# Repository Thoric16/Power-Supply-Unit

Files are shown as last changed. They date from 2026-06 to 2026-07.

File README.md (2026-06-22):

# Intelligent Power Distribution Unit (PSU) for Robotic Systems

A custom-designed, high-reliability Power Supply Unit (PSU) engineered to act as the centralized power management hub and hardware safety backbone for an advanced robotics platform. This board safely bridges high-draw actuator systems with sensitive compute electronics, featuring real-time telemetry and integrated fault protection.

---

## 🚀 Core Engineering Features

* **Centralized Voltage Regulation:** Features onboard step-down (buck) converters engineered to deliver clean, highly stable regulated voltage rails dedicated to sensitive compute units and sensor payloads.
* **Dynamic Power Routing:** Implements remotely switchable outputs, enabling upstream software to dynamically toggle power rails on-the-fly to conserve system energy or reset frozen peripherals.
* **Real-Time Current Monitoring:** Integrates inline current sensing architectures across critical nodes to detect electrical deviations, preventing overcurrent conditions from damaging hardware.
* **Hardware-Level Safety Architecture:** Interfaces natively with a physical Emergency Stop (E-Stop) loop, ensuring instantaneous, hardware-level power severance to high-draw chassis drivetrains and robotic arm actuators without relying on software loops.

---

## 🛠️ Technical Design & Specifications

### Hardware Breakdown
* **EDA Tooling:** Designed and routed entirely using KiCad.
* **Target Load Rails:** Dual-domain architecture isolating high-noise inductive motor spikes from digital logic logic rails.
* **Safety Controls:** Low-latency hardware isolation circuit mapped to the master system E-Stop button.

### Target Subsystem Map

| Managed Output Domain | Power Characteristic | Safety / Control Mechanism |
| :--- | :---: | :--- |
| **Compute Payloads** | Stable, Low-Noise Regulated | Upstream Overcurrent Monitored |
| **Sensor Electronics** | High-Precision Filtered | Soft-Switch Controlled |
| **Chassis Drivetrain** | High-Draw / Unregulated | Instantaneous Hardware E-Stop Cutoff |
| **Robotic Arm Drives** | High-Draw / Unregulated | Instantaneous Hardware E-Stop Cutoff |

---

## 💻 Hardware Layout & Physical Assembly

### Manufacturing & Routing Strategy
The PCB layout utilizes broad power planes and deliberate copper pours to handle high-current distribution safely while maintaining a tight, compact form factor. Signal lines for telemetry monitoring are physically isolated away from high-switching buck regulators to mitigate electromagnetic interference (EMI).

### Assembled Module View
Below is the physical validation of the manufactured and populated PSU PCB assembly:

Custom PSU Hardware Assembly

---

## 📁 Repository Navigation Guide

* `/hardware`: Contains the complete source schematic (`.kicad_sch`) and multi-layer board layout files (`.kicad_pcb`).
* `/assets`: High-resolution photographs.

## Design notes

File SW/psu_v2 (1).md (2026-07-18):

Zde je aktualizovaná dokumentace s přidanými poznámkami o zpoždění pro UDP multicast a DHCP fallback:

```markdown
# Komunikacni protokol pro napajeci jednotku (PSU) - PSU V2

Tato dokumentace popisuje komunikaci mezi ROS softwarem a mikrokontrolerem
W55RP20 EVB pro napajeci jednotku PSU. Aktualni navrh rozdeluje rizeni PSU na
dva nezavisle kanaly:

1. **TCP request-response** pro zapinani a vypinani power socketu.
2. **UDP multicast telemetry** pro prubezne posilani proudu a napeti.

---

## 1. Sitove nastaveni PSU

Preferovana varianta je DHCP:

- W55RP20 po startu pozada DHCP server o IP adresu.
- Po ziskani adresy zacne prijimat TCP prikazy a vysilat UDP multicast telemetrii.
- Pokud DHCP nebude dostupne, je mozne prejit na statickou IP adresu podle
  hlavni sitove dokumentace.

**Důležité časování při startu:**

- Po zapnutí zařízení je nutné počkat **10 sekund** na získání IP adresy od DHCP serveru.
- Pokud během této doby DHCP neodpoví, zařízení automaticky přejde na **fallback statickou IP adresu**.
- Fallback IP adresa: `172.16.10.20`
- Toto zpoždění zajišťuje, že síťové rozhraní je plně funkční před spuštěním dalších služeb.

Doporucena pevna identita v rover siti:

| Parametr | Hodnota |
| --- | --- |
| Zarizeni | `PICO-PSU` |
| Hostname | `pico-psu.perun-gen3.lan` |

---

## 2. TCP Request-Response pro power sockety

TCP se pouziva pro diskretni prikazy zapnuti a vypnuti power socketu.

Komunikaci vzdy iniciuje ROS:

- ROS otevre TCP spojeni na PSU.
- ROS odesle jeden `REQ` byte.
- W55RP20 provede nebo vyhodnoti prikaz.
- W55RP20 odesle jeden `RESP` byte.
- TCP spojeni se ukonci.

TCP spojeni neni persistentni a nepouziva se `keep-alive`.

### 2.1 TCP nastaveni

| Parametr | Hodnota |
| --- | --- |
| Protokol | TCP |
| Port | `50000` |
| Smer | `ROS -> PICO-PSU -> ROS` |
| Typ komunikace | Request-response |
| Persistentni spojeni | Ne |
| Keep-alive | Ne |

### 2.2 Format TCP requestu

Request ma velikost **1 byte**.

| Bity | Vyznam |
| --- | --- |
| 7-4 | Kod prikazu `CMD` |
| 3-0 | Argument prikazu `ARG` |

Obecne:

```text
REQ = (CMD << 4) | ARG
```

### 2.3 Format TCP response

Response ma velikost **1 byte**.

| Bity | Vyznam |
| --- | --- |
| 7-4 | Echo kodu prikazu `CMD` |
| 3-0 | Vysledek provedeni prikazu |

Dolni 4 bity odpovedi:

| Stav | Hodnota | Vyznam |
| --- | --- | --- |
| OK | puvodni argument + `8` | Prikaz byl prijat / proveden |
| FAIL | `0` | Prikaz selhal |

Obecne:

```text
RESP_OK   = (CMD << 4) | (ARG + 8)
RESP_FAIL = (CMD << 4) | 0
```

### 2.4 TCP prikazy pro power sockety

| Nazev | CMD | ARG | Popis |
| --- | --- | --- | --- |
| `POWER_SOCKET_ON` | `0001` | `0`-`7` | Zapne power socket 1 az 8 |
| `POWER_SOCKET_OFF` | `0010` | `0`-`7` | Vypne power socket 1 az 8 |

Kodovani socketu:

| Socket | ARG |
| --- | --- |
| 1 | `0` |
| 2 | `1` |
| 3 | `2` |
| 4 | `3` |
| 5 | `4` |
| 6 | `5` |
| 7 | `6` |
| 8 | `7` |

Toto kodovani je zvolene proto, aby slo jednoznacne rozlisit `OK` a `FAIL`.
Pri kodovani socketu jako `1`-`8` by odpoved `OK` pro socket 8 po pricteni `8`
pretekla v dolnich 4 bitech na `0`, tedy stejnou hodnotu jako `FAIL`.

Priklady:

| Request | Vyznam | Response OK | Response FAIL |
| --- | --- | --- | --- |
| `0001 0000` | Zapnout socket 1 | `0001 1000` | `0001 0000` |
| `0001 0111` | Zapnout socket 8 | `0001 1111` | `0001 0000` |
| `0010 0000` | Vypnout socket 1 | `0010 1000` | `0010 0000` |
| `0010 0111` | Vypnout socket 8 | `0010 1111` | `0010 0000` |

---

## 3. UDP Multicast Telemetry

UDP multicast se pouziva pro prubezne posilani telemetrie z PSU do ROS.

Telemetry tok jde smerem:

```text
PICO-PSU -> ROS
```

ROS se pripoji do odpovidajici multicast skupiny a prijima telemetry packety.

### 3.1 Multicast nastaveni

| Parametr | Hodnota |
| --- | --- |
| Multicast group | `239.192.1.100` |
| Port | `49151` |
| Protokol | UDP multicast |
| Smer | `PICO-PSU -> ROS` |
| Frekvence | Dle nastaveni Pico |
| Endianness | Little-Endian |

**Důležité omezení pro odesílání telemetrie:**

- Aby nedocházelo k zahlcení sítě a ROS systému, je třeba dodržet **minimální interval mezi jednotlivými UDP zprávami**.
- **Doporučený interval:** **1 sekunda** mezi jednotlivými telemetrickými zprávami.
- To znamená, že PSU nebude odesílat telemetrii častěji než jednou za sekundu. 
- Toto opatření zajišťuje stabilní přenos a předchází ztrátám paketů v síti.

### 3.2 Format UDP telemetry packetu

Packet ma pevnou velikost **40 bajtu**.

Data jsou odesilana jako binarni blok v tomto poradi:

| Poradi | Datovy typ | Velikost | Nazev | Popis |
| --- | --- | --- | --- | --- |
| 1 | `float[5]` | 20 B | `current_cells_1_5` | Proud na clancich 1 az 5, kazdy clanek samostatne |
| 2 | `float` | 4 B | `current_cells_6_8` | Proud na clancich 6 az 8 spolecne |
| 3 | `float` | 4 B | `voltage_cells_1_5` | Napeti na clancich 1 az 5 spolecne |
| 4 | `float` | 4 B | `voltage_cells_6_8` | Napeti na clancich 6 az 8 spolecne |
| 5 | `float` | 4 B | `current` | Celkovy output proud |
| 6 | `float` | 4 B | `state_of_charge` | Procentualni nabiti baterky; cislo 0.0 az 1.0 |

Celkovy output voltage je stejny jako `voltage_cells_1_5`
```

---

## Shrnutí přidaných změn:

1. **Do sekce 1 (Síťové nastavení)** přidáno:
   - Po startu čekat 10s na DHCP
   - Fallback IP adresa `172.16.10.20`
   - Popis, že teprve po této době se spouští ostatní služby

2. **Do sekce 3.1 (Multicast nastavení)** přidáno:
   - Omezení minimálního intervalu 1s mezi UDP zprávami
   - Zdůvodnění (zabránění zahlcení sítě, stabilita přenosu)

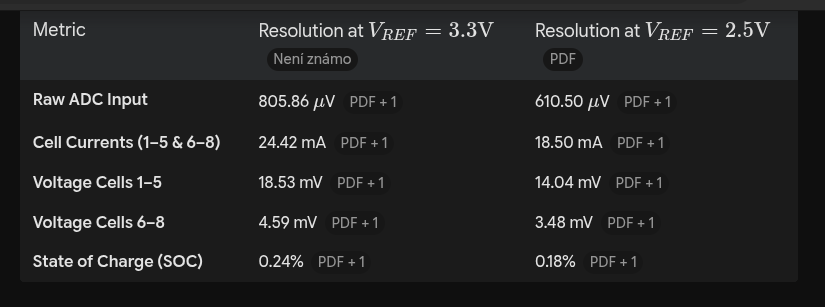
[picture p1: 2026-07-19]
SW/image.png

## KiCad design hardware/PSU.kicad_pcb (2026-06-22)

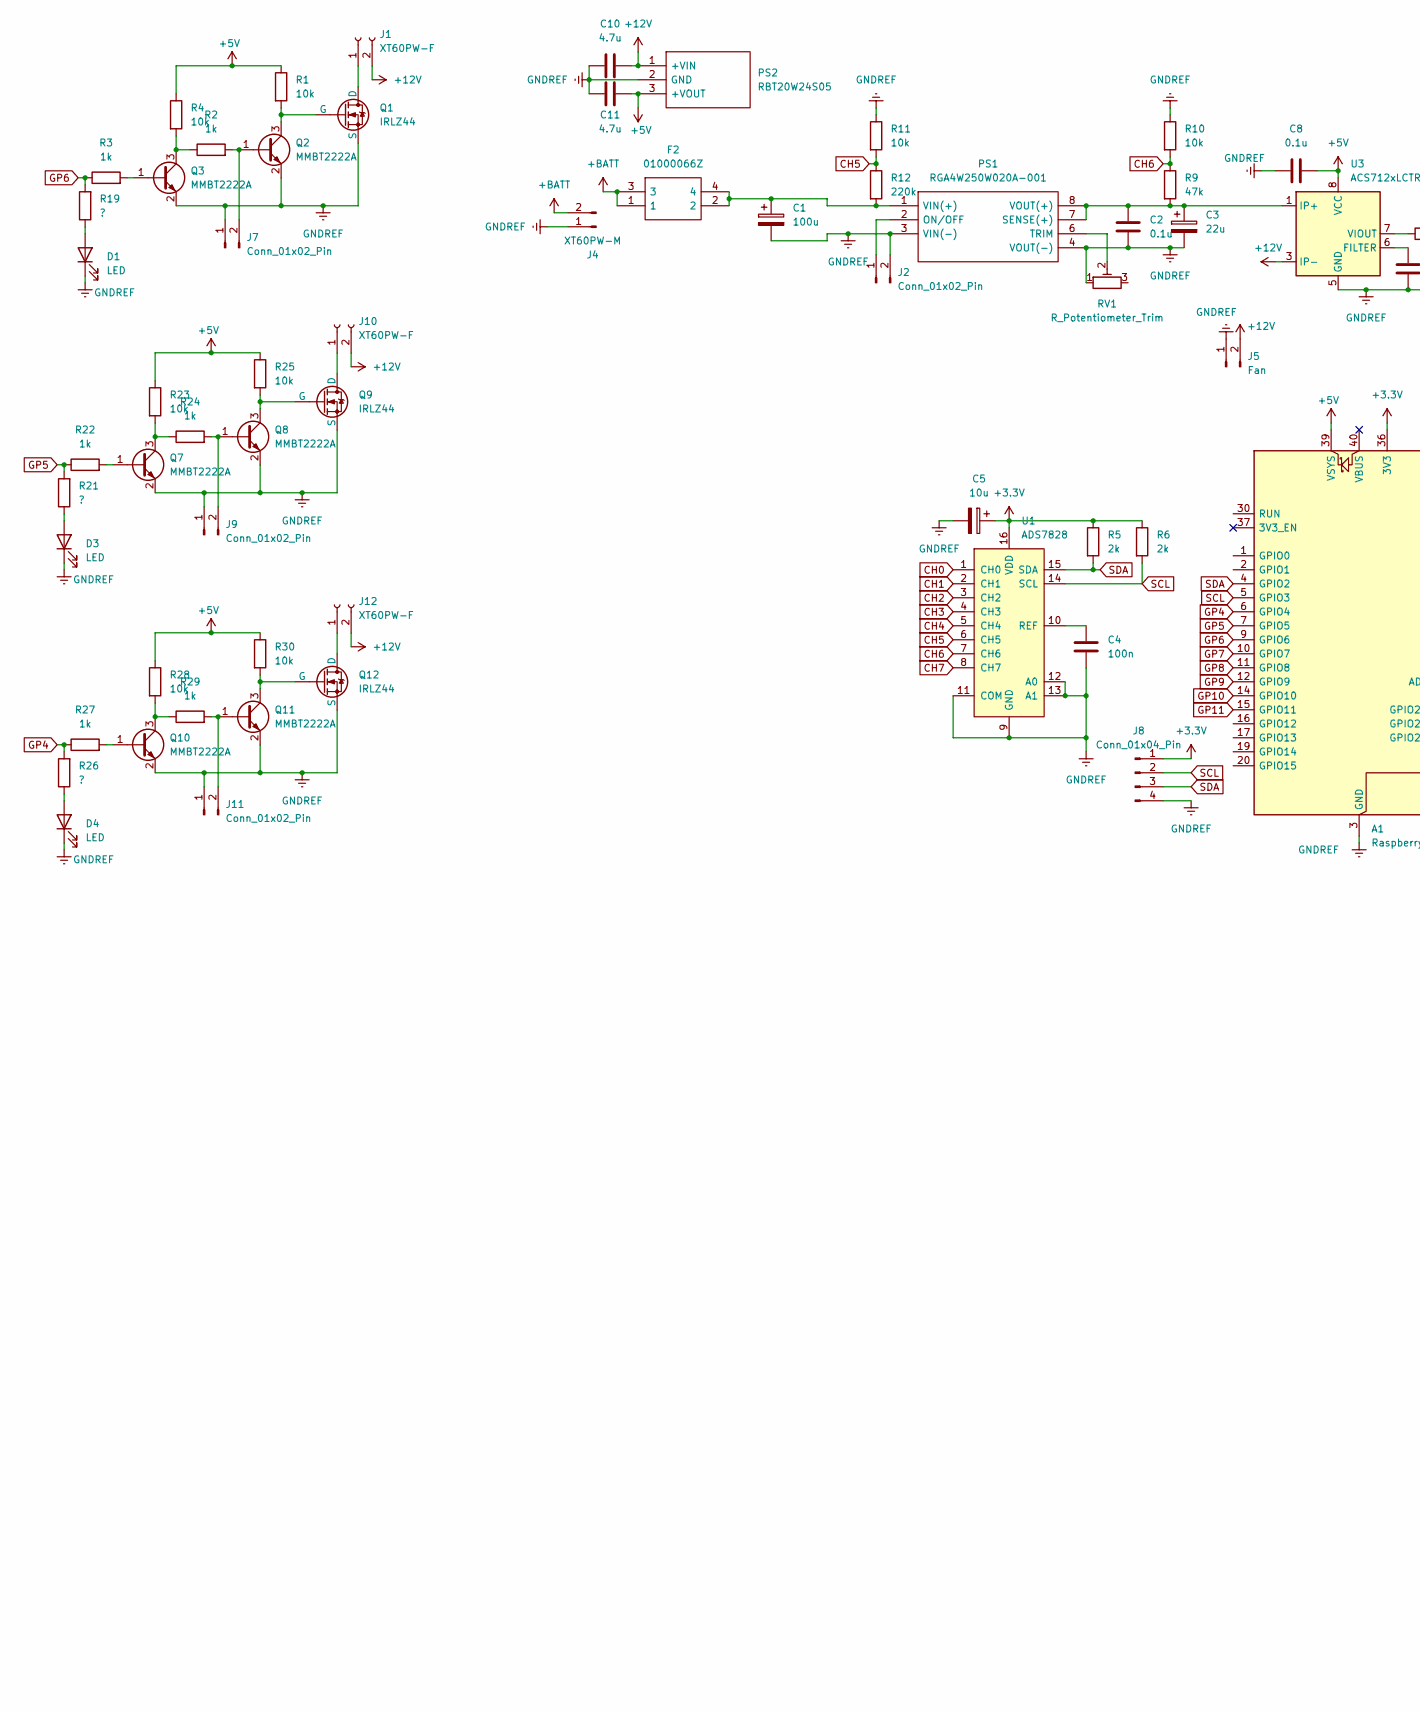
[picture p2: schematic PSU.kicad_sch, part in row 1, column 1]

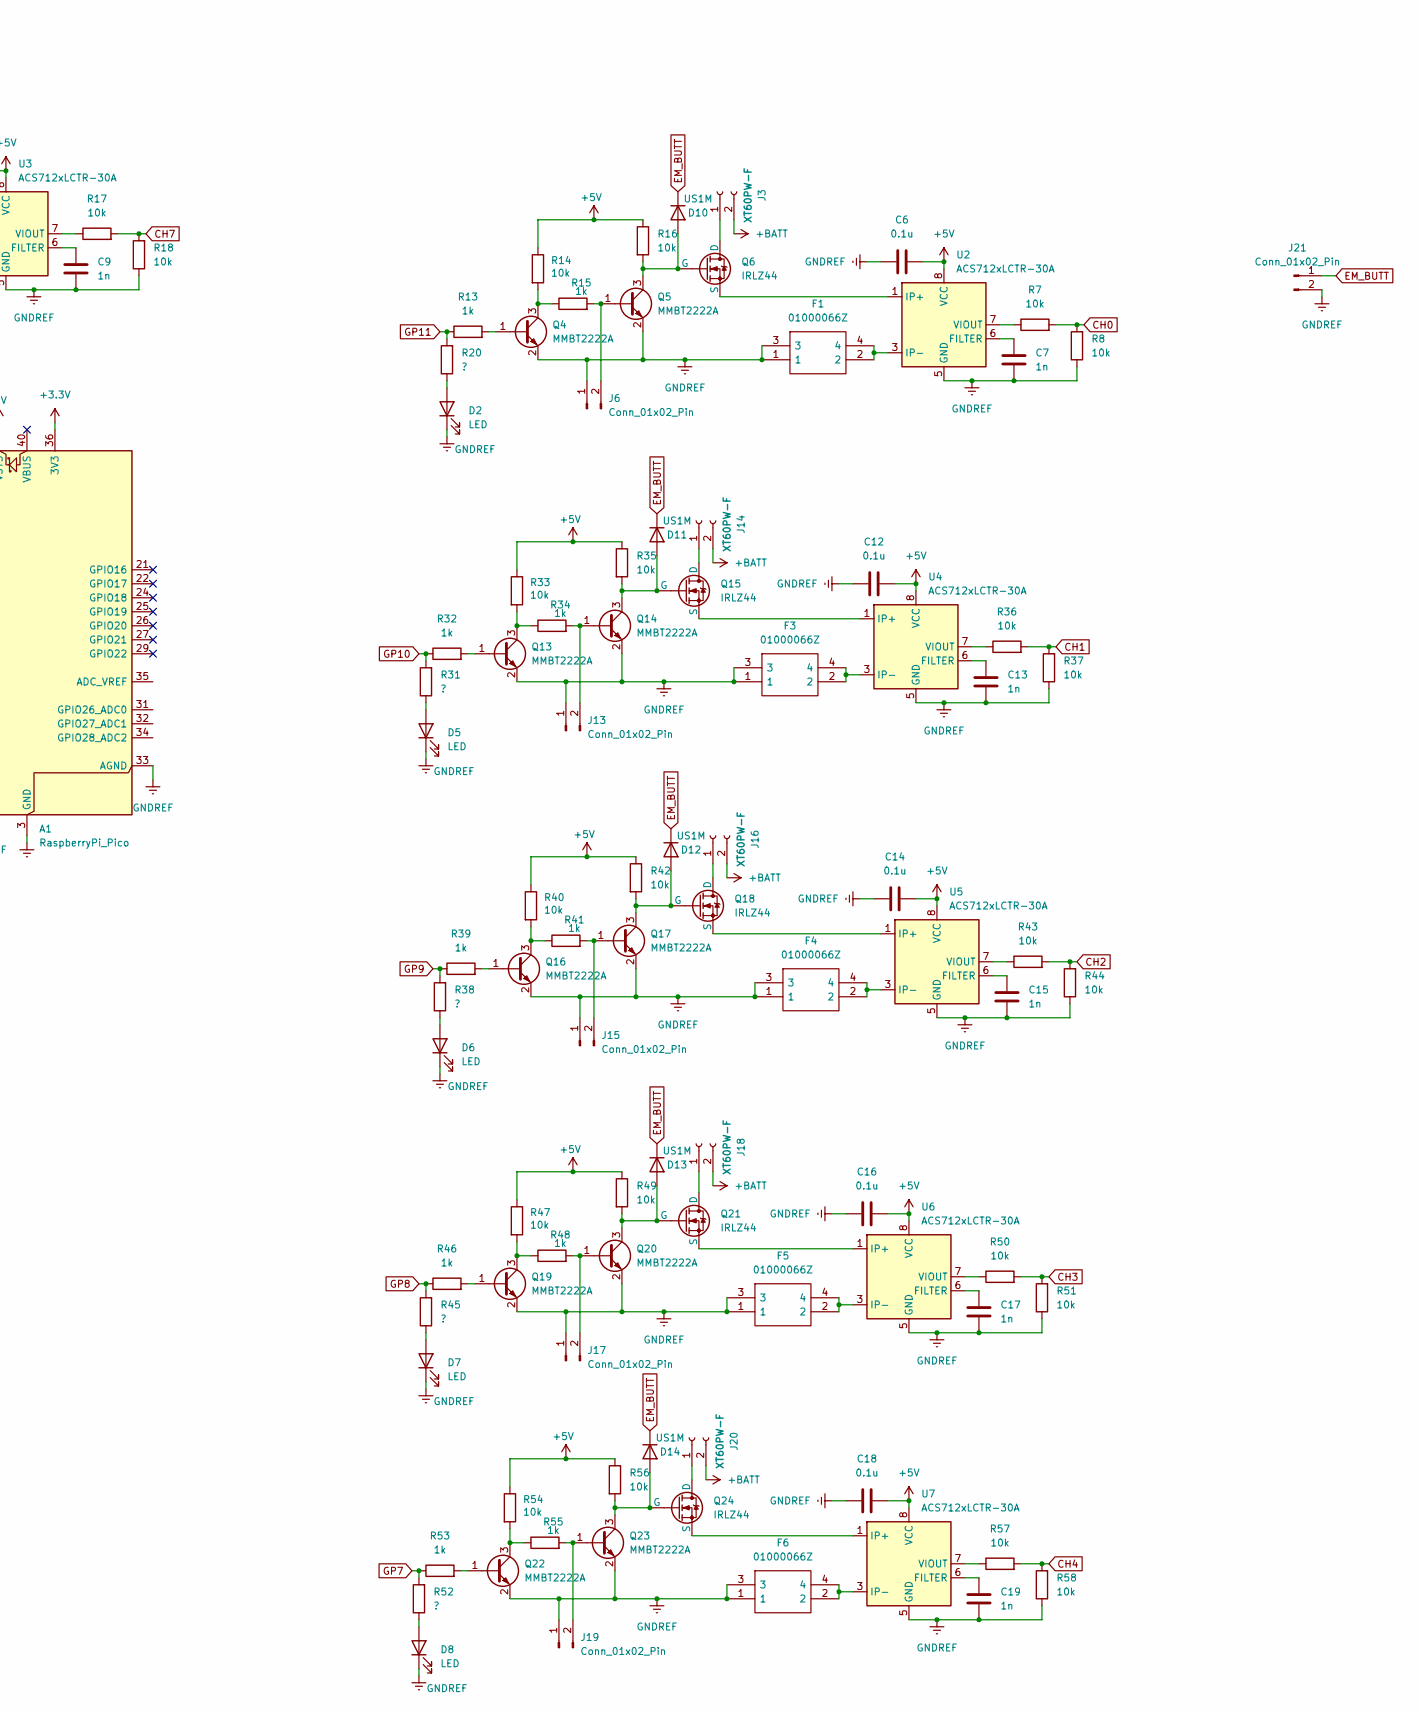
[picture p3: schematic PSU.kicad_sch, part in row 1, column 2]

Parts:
A1: RaspberryPi_Pico; RaspberryPi_Pico_Common_THT
C1: 100u; CP_Elec_10x10.5
C2, C6, C8, C12, C14, C16, C18: 0.1u; C_0603_1608Metric
C3: 22u; CP_Elec_8x6.2
C4: 100n; C_0603_1608Metric
C5: 10u; C_0603_1608Metric
C7, C9, C13, C15, C17, C19: 1n; C_0603_1608Metric
C10, C11: 4.7u; C_0603_1608Metric
D1, D2, D3, D4, D5, D6, D7, D8: LED; LED_0603_1608Metric
D10, D11, D12, D13, D14: US1M; D_SMA
F1, F2, F3, F4, F5, F6: 01000066Z; Mouser Part Number 576-01000066Z
J1, J3, J10, J12, J14, J16, J18, J20: XT60PW-F; AMASS_XT60PW-F_1x02_P7.20mm_Horizontal
J2, J6, J7, J9, J11, J13, J15, J17, J19, J21: Conn_01x02_Pin; PinSocket_1x02_P2.54mm_Vertical
J4: XT60PW-M; AMASS_XT60PW-M_1x02_P7.20mm_Horizontal
J5: Fan; PinSocket_1x02_P2.54mm_Vertical
J8: Conn_01x04_Pin; PinHeader_1x04_P2.54mm_Vertical
PS1: RGA4W250W020A-001; RGA4W250W020A001; Mouser Part Number 967-RGA4W250W020A001
PS2: RBT20W24S05; Manufacturer_Part_Number RBT20W24S05
Q1, Q6, Q9, Q12, Q15, Q18, Q21, Q24: IRLZ44; TO-220-3_Vertical_custom
Q2, Q3, Q4, Q5, Q7, Q8, Q10, Q11, Q13, Q14, Q16, Q17, Q19, Q20, Q22, Q23: MMBT2222A; SOT-23
R1, R4, R7, R8, R10, R11, R14, R16, R17, R18, R23, R25, R28, R30, R33, R35, R36, R37, R40, R42, R43, R44, R47, R49, R50, R51, R54, R56, R57, R58: 10k; R_0603_1608Metric
R2, R3, R13, R15, R22, R24, R27, R29, R32, R34, R39, R41, R46, R48, R53, R55: 1k; R_0603_1608Metric
R5, R6: 2k; R_0603_1608Metric
R9: 47k; R_0603_1608Metric
R12: 220k; R_0603_1608Metric
R19, R20, R21, R26, R31, R38, R45, R52: ?; R_0603_1608Metric
RV1: R_Potentiometer_Trim; Potentiometer_Bourns_3296W_Vertical
U1: ADS7828; TSSOP-16_4.4x5mm_P0.65mm
U2, U3, U4, U5, U6, U7: ACS712xLCTR-30A; SOIC-8_3.9x4.9mm_P1.27mm

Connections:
+3.3V: A1.36 (3V3), C5.1, J8.1, R5.1, R6.1, U1.16 (VDD)
+5V: A1.39 (VSYS), C6.2, C8.2, C11.2, C12.2, C14.2, C16.2, C18.2, PS2.3 (+VOUT), R1.1, R4.1, R14.1, R16.1, R23.1, R25.1, R28.1, R30.1, R33.1, R35.1, R40.1, R42.1, R47.1, R49.1, R54.1, R56.1, U2.8 (VCC), U3.8 (VCC), U4.8 (VCC), U5.8 (VCC), U6.8 (VCC), U7.8 (VCC)
+12V: C10.2, J1.2, J5.2, J10.2, J12.2, PS2.1 (+VIN), U3.3 (IP-), U3.4 (IP-)
+BATT: F2.1, F2.3, J3.2, J4.2, J14.2, J16.2, J18.2, J20.2
CH0: R7.2, R8.2, U1.1 (CH0)
CH1: R36.2, R37.2, U1.2 (CH1)
CH2: R43.2, R44.2, U1.3 (CH2)
CH3: R50.2, R51.2, U1.4 (CH3)
CH4: R57.2, R58.2, U1.5 (CH4)
CH5: R11.2, R12.1, U1.6 (CH5)
CH6: R9.1, R10.2, U1.7 (CH6)
CH7: R17.2, R18.2, U1.8 (CH7)
EM_BUTT: D10.1 (K), D11.1 (K), D12.1 (K), D13.1 (K), D14.1 (K), J21.1
GNDREF: A1.3 (GND), A1.8 (GND), A1.13 (GND), A1.18 (GND), A1.23 (GND), A1.28 (GND), A1.33 (AGND), A1.38 (GND), C1.2, C2.2, C3.2, C4.2, C5.2, C6.1, C7.1, C8.1, C9.1, C10.1, C11.1, C12.1, C13.1, C14.1, C15.1, C16.1, C17.1, C18.1, C19.1, D1.1 (K), D2.1 (K), D3.1 (K), D4.1 (K), D5.1 (K), D6.1 (K), D7.1 (K), D8.1 (K), F1.1, F1.3, F3.1, F3.3, F4.1, F4.3, F5.1, F5.3, F6.1, F6.3, J2.2, J4.1, J5.1, J6.1, J7.1, J8.4, J9.1, J11.1, J13.1, J15.1, J17.1, J19.1, J21.2, PS1.3 (VIN(-)), PS1.4 (VOUT(-)), PS2.2 (GND), Q1.3 (S), Q2.2 (E), Q3.2 (E), Q4.2 (E), Q5.2 (E), Q7.2 (E), Q8.2 (E), Q9.3 (S), Q10.2 (E), Q11.2 (E), Q12.3 (S), Q13.2 (E), Q14.2 (E), Q16.2 (E), Q17.2 (E), Q19.2 (E), Q20.2 (E), Q22.2 (E), Q23.2 (E), R8.1, R10.1, R11.1, R18.1, R37.1, R44.1, R51.1, R58.1, RV1.1, U1.9 (GND), U1.11 (COM), U1.12 (A0), U1.13 (A1), U2.5 (GND), U3.5 (GND), U4.5 (GND), U5.5 (GND), U6.5 (GND), U7.5 (GND)
GP4: A1.6 (GPIO4), R26.2, R27.1
GP5: A1.7 (GPIO5), R21.2, R22.1
GP6: A1.9 (GPIO6), R3.1, R19.2
GP7: A1.10 (GPIO7), R52.2, R53.1
GP8: A1.11 (GPIO8), R45.2, R46.1
GP9: A1.12 (GPIO9), R38.2, R39.1
GP10: A1.14 (GPIO10), R31.2, R32.1
GP11: A1.15 (GPIO11), R13.1, R20.2
unnamed: D1.2 (A), R19.1
unnamed: D2.2 (A), R20.1
unnamed: D3.2 (A), R21.1
unnamed: D4.2 (A), R26.1
unnamed: D5.2 (A), R31.1
unnamed: D6.2 (A), R38.1
unnamed: D7.2 (A), R45.1
unnamed: D8.2 (A), R52.1
unnamed: D10.2 (A), Q5.3 (C), Q6.2 (G), R16.2
unnamed: D11.2 (A), Q14.3 (C), Q15.2 (G), R35.2
unnamed: D12.2 (A), Q17.3 (C), Q18.2 (G), R42.2
unnamed: D13.2 (A), Q20.3 (C), Q21.2 (G), R49.2
unnamed: D14.2 (A), Q23.3 (C), Q24.2 (G), R56.2
unnamed: F1.2, F1.4, U2.3 (IP-), U2.4 (IP-)
unnamed: F3.2, F3.4, U4.3 (IP-), U4.4 (IP-)
unnamed: F4.2, F4.4, U5.3 (IP-), U5.4 (IP-)
unnamed: F5.2, F5.4, U6.3 (IP-), U6.4 (IP-)
unnamed: F6.2, F6.4, U7.3 (IP-), U7.4 (IP-)
unnamed: J1.1, Q1.1 (D)
unnamed: J2.1, PS1.2 (ON/OFF)
unnamed: J3.1, Q6.1 (D)
unnamed: J6.2, Q5.1 (B), R15.2
unnamed: J7.2, Q2.1 (B), R2.2
unnamed: J9.2, Q8.1 (B), R24.2
unnamed: J10.1, Q9.1 (D)
unnamed: J11.2, Q11.1 (B), R29.2
unnamed: J12.1, Q12.1 (D)
unnamed: J13.2, Q14.1 (B), R34.2
unnamed: J14.1, Q15.1 (D)
unnamed: J15.2, Q17.1 (B), R41.2
unnamed: J16.1, Q18.1 (D)
unnamed: J17.2, Q20.1 (B), R48.2
unnamed: J18.1, Q21.1 (D)
unnamed: J19.2, Q23.1 (B), R55.2
unnamed: J20.1, Q24.1 (D)
unnamed: C2.1, C3.1, PS1.7 (SENSE(+)), PS1.8 (VOUT(+)), R9.2, U3.1 (IP+), U3.2 (IP+)
unnamed: PS1.6 (TRIM), RV1.2
unnamed: C1.1, F2.2, F2.4, PS1.1 (VIN(+)), R12.2
unnamed: Q1.2 (G), Q2.3 (C), R1.2
unnamed: Q3.1 (B), R3.2
unnamed: Q3.3 (C), R2.1, R4.2
unnamed: Q4.1 (B), R13.2
unnamed: Q4.3 (C), R14.2, R15.1
unnamed: Q6.3 (S), U2.1 (IP+), U2.2 (IP+)
unnamed: Q7.1 (B), R22.2
unnamed: Q7.3 (C), R23.2, R24.1
unnamed: Q8.3 (C), Q9.2 (G), R25.2
unnamed: Q10.1 (B), R27.2
unnamed: Q10.3 (C), R28.2, R29.1
unnamed: Q11.3 (C), Q12.2 (G), R30.2
unnamed: Q13.1 (B), R32.2
unnamed: Q13.3 (C), R33.2, R34.1
unnamed: Q15.3 (S), U4.1 (IP+), U4.2 (IP+)
unnamed: Q16.1 (B), R39.2
unnamed: Q16.3 (C), R40.2, R41.1
unnamed: Q18.3 (S), U5.1 (IP+), U5.2 (IP+)
unnamed: Q19.1 (B), R46.2
unnamed: Q19.3 (C), R47.2, R48.1
unnamed: Q21.3 (S), U6.1 (IP+), U6.2 (IP+)
unnamed: Q22.1 (B), R53.2
unnamed: Q22.3 (C), R54.2, R55.1
unnamed: Q24.3 (S), U7.1 (IP+), U7.2 (IP+)
unnamed: C4.1, U1.10 (REF)
unnamed: C7.2, U2.6 (FILTER)
unnamed: R7.1, U2.7 (VIOUT)
unnamed: C9.2, U3.6 (FILTER)
unnamed: R17.1, U3.7 (VIOUT)
unnamed: C13.2, U4.6 (FILTER)
unnamed: R36.1, U4.7 (VIOUT)
unnamed: C15.2, U5.6 (FILTER)
unnamed: R43.1, U5.7 (VIOUT)
unnamed: C17.2, U6.6 (FILTER)
unnamed: R50.1, U6.7 (VIOUT)
unnamed: C19.2, U7.6 (FILTER)
unnamed: R57.1, U7.7 (VIOUT)
SCL: A1.5 (GPIO3), J8.2, R6.2, U1.14 (SCL)
SDA: A1.4 (GPIO2), J8.3, R5.2, U1.15 (SDA)

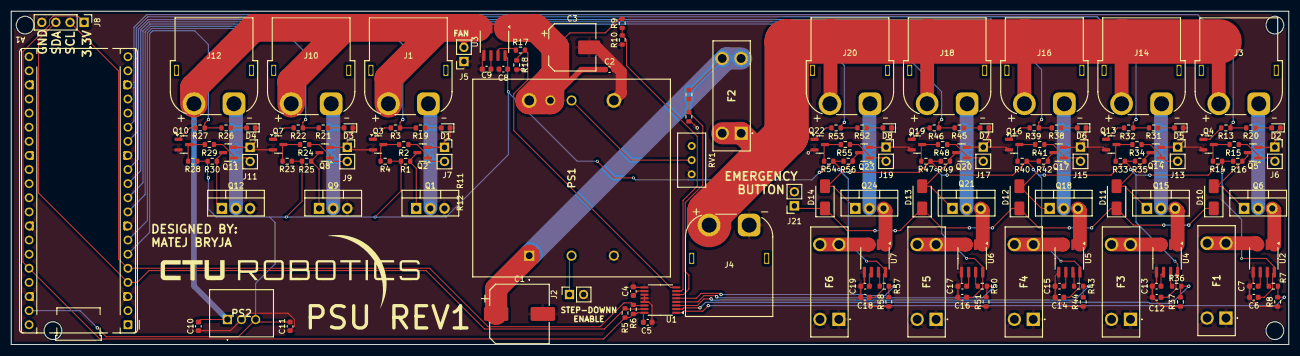
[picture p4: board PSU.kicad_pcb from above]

Board: 4 copper layers, 230.0 x 60.0 mm, 152 parts (0 on the bottom side), 99 nets.

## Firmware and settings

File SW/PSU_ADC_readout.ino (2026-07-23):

#include <SPI.h>
#include <SoftwareSPI.h>
#include <W5500lwIP.h>
#include <WiFiServer.h>
#include <WiFiClient.h>
#include <WiFiUdp.h>
#include <Wire.h>

// ==========================================
// KONFIGURÁCIA SIETE 
// ==========================================
byte mac[] = { 0x00, 0x08, 0xDC, 0x11, 0x22, 0x33 };
IPAddress staticIP(192, 168, 1, 100);

// W55RP20 Interné piny
#define PIN_SCK 21
#define PIN_MISO 22
#define PIN_MOSI 23
#define PIN_CS 20
#define PIN_RST 25
#define PIN_IRQ 24

SoftwareSPI wizSPI(PIN_SCK, PIN_MISO, PIN_MOSI);
Wiznet5500lwIP eth(PIN_CS, wizSPI, PIN_IRQ);

// TCP Server
const uint16_t TCP_PORT = 50000;
WiFiServer tcpServer(TCP_PORT);

// UDP Multicast
WiFiUDP udp;
IPAddress multicastIP(239, 192, 1, 100);
const uint16_t UDP_PORT = 49150;
const unsigned long TELEMETRY_INTERVAL_MS = 100; // 10 Hz
unsigned long lastTelemetryTime = 0;

// ==========================================
// DEBUG A SÉRIOVÁ LINKA
// ==========================================
unsigned long lastSerialDebugTime = 0;
const unsigned long SERIAL_DEBUG_INTERVAL_MS = 1000; // 1 Hz
bool serialTelemetryEnabled = true;

// ==========================================
// HARDVÉROVÉ MAPOVANIE A KONŠTANTY
// ==========================================
// Socket 1-8 -> GP11-GP4 (Indexované od 0)
const int socketPins[8] = {11, 10, 9, 8, 7, 6, 5, 4};

// I2C (Wire1 pre GP2 a GP3)
const int I2C_SDA = 2;
const int I2C_SCL = 3;
const uint8_t ADS7828_ADDR = 0x48;

// Výpočetné konštanty
const float V_REF = 2.5;             
const float ACS_OFFSET = 2.5;        
const float ACS_SENSITIVITY = 0.066; // 30A verzia: 66 mV/A
const float BATTERY_V_MIN = 3.5*11; 
const float BATTERY_V_MAX = 4.2*11; 

// ==========================================
// DÁTOVÉ ŠTRUKTÚRY
// ==========================================
struct __attribute__((packed)) TelemetryPacket {
  float current_cells_1_5[5];
  float current_cells_6_8;
  float voltage_cells_1_5;
  float voltage_cells_6_8;
  float current;
  float state_of_charge;
  uint8_t rover_armed; // PRIDANE: 0=disarmed, 1=armed (1 Byte)
};

TelemetryPacket telemetryData;

// ==========================================
// POMOCNÉ FUNKCIE
// ==========================================
uint16_t readADS7828(uint8_t channel) {
  if (channel > 7) return 0;
  const uint8_t ch_map[8] = {0x00, 0x40, 0x10, 0x50, 0x20, 0x60, 0x30, 0x70};
  uint8_t cmd = 0x8C | ch_map[channel];

  Wire1.beginTransmission(ADS7828_ADDR);
  Wire1.write(cmd);
  Wire1.endTransmission();

  Wire1.requestFrom(ADS7828_ADDR, (uint8_t)2);
  if (Wire1.available() >= 2) {
    uint8_t msb = Wire1.read();
    uint8_t lsb = Wire1.read();
    return (msb << 8) | lsb; 
  }
  return 0;
}

// ==========================================
// SETUP
// ==========================================
void setup() {
  Serial.begin(115200);
  delay(2000); 
  Serial.println("\n--- PICO-PSU V2 STARTING ---");
  
  // Inicializacia telemetrie
  telemetryData.rover_armed = 1; // PRIDANE: Vychodzi stav disarmed

  // 1. Inicializácia Socketov
  Serial.println("Inicializujem sockety (GP11-GP4)...");
  for (int i = 0; i < 7; i++) {
    pinMode(socketPins[i], OUTPUT);
    digitalWrite(socketPins[i], HIGH);
    delay(200);
  }
  int pin = socketPins[7];
  pinMode(pin, OUTPUT);

  int steps = 5000;           // 100 steps over 1 second
  int periodMicros = 1000;  // 10 ms total per cycle (100 Hz refresh rate)

  for (int step = 0; step < steps; step++) {
    // Calculate ON time proportionally (0 µs up to 10,000 µs)
    int highTime = map(step, 0, steps, 0, periodMicros);
    int lowTime  = periodMicros - highTime;

    digitalWrite(pin, HIGH);
    delayMicroseconds(highTime);
    
    digitalWrite(pin, LOW);
    delayMicroseconds(lowTime);
  }

  // Lock it HIGH at full power after the ramp finishes
  digitalWrite(pin, HIGH);

  // 2. Inicializácia I2C (Wire1)
  Serial.println("Inicializujem I2C pre ADS7828 na Wire1...");
  Wire1.setSDA(I2C_SDA);
  Wire1.setSCL(I2C_SCL);
  Wire1.begin();

  // 3. Inicializácia W5500 (SoftwareSPI + lwIP)
  Serial.println("Inicializujem siet W5500...");
  pinMode(PIN_RST, OUTPUT);
  digitalWrite(PIN_RST, LOW);
  delay(10);
  digitalWrite(PIN_RST, HIGH);
  delay(50);

  eth.setSPISpeed(20000000);
  
  if (!eth.begin(mac)) {
    Serial.println("-> HW chyba: W5500 nenajdeny!");
  } else {
    Serial.print("Pripojovanie k DHCP...");
    unsigned long startDHCP = millis();
    
    // Čakáme max 10 sekúnd na DHCP, aby to neblokovalo bez kábla
    while (eth.localIP() == IPAddress(0,0,0,0) && (millis() - startDHCP < 10000)) {
      delay(500);
      Serial.print(".");
    }
    
    if (eth.localIP() == IPAddress(0,0,0,0)) {
      Serial.println("\n-> DHCP timeout! Pouzivam staticku IP.");
      eth.config(staticIP, IPAddress(172, 16, 10, 20), IPAddress(255, 255, 255, 0));
    } else {
      Serial.println("\n-> DHCP uspesne.");
    }
  }

  Serial.print("PSU IP Adresa: ");
  Serial.println(eth.localIP());

  // Štart serverov
  tcpServer.begin();
  
  // Multicast pripojenie
  udp.beginMulticast(multicastIP, UDP_PORT);
  
  Serial.println("-------------------------------------------------");
  Serial.println("TCP Server bezi na porte 50000.");
  Serial.println("Ovladanie cez Serial: 'ON x' alebo 'OFF x' (x = 1-8)");
  Serial.println("Pre telemetriu: 'TEL ON' alebo 'TEL OFF'");
  Serial.println("-------------------------------------------------\n");
}

// ==========================================
// HLAVNÁ SLUČKA (LOOP)
// ==========================================
void loop() {
  handleTCP();
  handleSerialCommands();

  // UDP telemetria v intervale
  if (millis() - lastTelemetryTime >= TELEMETRY_INTERVAL_MS) {
    lastTelemetryTime = millis();
    updateAndSendTelemetry();
  }
}

// ==========================================
// SÉRIOVÉ OVLÁDANIE
// ==========================================
void handleSerialCommands() {
  if (Serial.available() > 0) {
    String input = Serial.readStringUntil('\n');
    input.trim();
    input.toUpperCase(); 

    if (input.length() == 0) return;

    if (input.startsWith("ON ")) {
      int socket = input.substring(3).toInt();
      if (socket >= 1 && socket <= 8) {
        digitalWrite(socketPins[socket - 1], HIGH);
        Serial.print("[SERIAL] -> ZAPINAM socket "); Serial.println(socket);
      }
    } 
    else if (input.startsWith("OFF ")) {
      int socket = input.substring(4).toInt();
      if (socket >= 1 && socket <= 8) {
        digitalWrite(socketPins[socket - 1], LOW);
        Serial.print("[SERIAL] -> VYPINAM socket "); Serial.println(socket);
      }
    } 
    else if (input == "TEL ON") {
      serialTelemetryEnabled = true;
      Serial.println("[SERIAL] -> Telemetria ZAPNUTA");
    }
    else if (input == "TEL OFF") {
      serialTelemetryEnabled = false;
      Serial.println("[SERIAL] -> Telemetria VYPNUTA");
    }
  }
}

// ==========================================
// TCP REQUEST-RESPONSE
// ==========================================
void handleTCP() {
  WiFiClient client = tcpServer.available();
  if (client) {
    if (client.connected() && client.available() > 0) {
      uint8_t req = client.read();
      uint8_t cmd = (req >> 4) & 0x0F;
      uint8_t arg = req & 0x0F;
      uint8_t resp = 0;

      Serial.print("[TCP] Prijate: 0x"); Serial.print(req, HEX);
      Serial.print(" (CMD="); Serial.print(cmd); Serial.print(", ARG="); Serial.print(arg); Serial.println(")");

      if ((cmd == 0x01 || cmd == 0x02) && (arg <= 7)) {
        digitalWrite(socketPins[arg], (cmd == 0x01) ? HIGH : LOW);
        resp = (cmd << 4) | (arg + 8); // OK response
        
        Serial.print("[TCP] -> Akcia: ");
        Serial.print((cmd == 0x01) ? "ZAPNUTY" : "VYPNUTY");
        Serial.print(" Socket "); Serial.println(arg + 1); 
      } 
      // PRIDANE: ROVER_ARM
      else if (cmd == 0x03 && arg == 0) {
        telemetryData.rover_armed = 1;
        resp = (cmd << 4) | (arg + 8); // OK response
        Serial.println("[TCP] -> Akcia: ROVER_ARM");
      }
      // PRIDANE: ROVER_DISARM
      else if (cmd == 0x04 && arg == 0) {
        telemetryData.rover_armed = 0;
        resp = (cmd << 4) | (arg + 8); // OK response
        Serial.println("[TCP] -> Akcia: ROVER_DISARM");
      } 
      else {
        resp = (cmd << 4) | 0; // FAIL response
        Serial.println("[TCP] -> Akcia ZAMIETNUTA");
      }
      
      client.write(resp);
    }
    client.stop(); // Vždy okamžite uzavrieť spojenie
  }
}

// ==========================================
// SPRACOVANIE A ODOSLANIE TELEMETRIE
// ==========================================
void updateAndSendTelemetry() {

  // Detekcia stavu disarm pomocou interneho Pico ADC2 (GP28)
  int raw_adc2_pico = analogRead(28);
  // Arduino core pre Pico ma default 10-bit (0-1023) a 3.3V referenciu
  float v_gate = (raw_adc2_pico / 1023.0) * 3.3; 

  if (v_gate < 0.1) {
    telemetryData.rover_armed = 0; // Software disarm (~0.0V)
  } else if (v_gate >= 0.1 && v_gate < 0.5) {
    telemetryData.rover_armed = 2; // Physical E-Stop (~0.2V)
  } else {
    telemetryData.rover_armed = 1; // Armed (~3.3V)
  }


  float total_current = 0.0;

  // Prúd články 1-5 (ADC 0-4)
  for (int i = 0; i < 5; i++) {
    uint16_t raw_adc = readADS7828(i);
    float v_adc = (raw_adc / 4095.0) * V_REF;
    float v_sensor = v_adc * 2.0; 
    float current = (v_sensor - ACS_OFFSET) / ACS_SENSITIVITY;
    
    
    if (abs(current) < 0.1) current = 0.0;
    
    telemetryData.current_cells_1_5[i] = current;
    total_current += current;
  }

  // Prúd články 6-8 (ADC 7)
  uint16_t raw_i_6_8 = readADS7828(7);
  float v_adc_i_6_8 = (raw_i_6_8 / 4095.0) * V_REF;
  float v_sensor_i_6_8 = v_adc_i_6_8 * 2.0; 
  float current_6_8 = (v_sensor_i_6_8 - ACS_OFFSET) / ACS_SENSITIVITY;
  
  if (abs(current_6_8) < 0.1) current_6_8 = 0.0;
  telemetryData.current_cells_6_8 = current_6_8;
  total_current += 0.31*current_6_8;

  telemetryData.current = total_current;

  // Napätie 1-5 (ADC 5)
  uint16_t raw_v_1_5 = readADS7828(5);
  float v_adc_1_5 = (raw_v_1_5 / 4095.0) * V_REF;
  telemetryData.voltage_cells_1_5 = v_adc_1_5 * (((220.0 + 10.0) / 10.0));

  // Napätie 6-8 (ADC 6)
  uint16_t raw_v_6_8 = readADS7828(6);
  float v_adc_6_8 = (raw_v_6_8 / 4095.0) * V_REF;
  telemetryData.voltage_cells_6_8 = v_adc_6_8 * (((47.0 + 10.0) / 10.0));

  // State of Charge (SOC)
  float soc = (telemetryData.voltage_cells_1_5 - BATTERY_V_MIN) / (BATTERY_V_MAX - BATTERY_V_MIN);
  if (soc > 1.0) soc = 1.0;
  if (soc < 0.0) soc = 0.0;
  telemetryData.state_of_charge = soc;

  // Odoslanie UDP
  // Uistíme sa, že je vytvorená správna multicast štruktúra hlavičky pre lwIP
  udp.beginPacket(multicastIP, UDP_PORT);
  udp.write((uint8_t*)&telemetryData, sizeof(TelemetryPacket));
  udp.endPacket();

  // Sériový výpis debug telemetrie
  if (serialTelemetryEnabled && (millis() - lastSerialDebugTime >= SERIAL_DEBUG_INTERVAL_MS)) {
    lastSerialDebugTime = millis();
    Serial.println("\n[TELEMETRIA]");
    
    Serial.print("  Prudy 1-5 [A]: ");
    for (int i = 0; i < 5; i++) {
      Serial.print(telemetryData.current_cells_1_5[i], 2);
      Serial.print("  ");
    }
    Serial.println();
    
    Serial.print("  Prud  6-8 [A]: "); Serial.println(telemetryData.current_cells_6_8, 2);
    Serial.print("  Prud Celk [A]: "); Serial.println(telemetryData.current, 2);
    Serial.print("  Napatie 1-5 [V]: "); Serial.println(telemetryData.voltage_cells_1_5, 2);
    Serial.print("  Napatie 6-8 [V]: "); Serial.println(telemetryData.voltage_cells_6_8, 2);
    Serial.print("  SOC        [%]: "); Serial.println(telemetryData.state_of_charge * 100.0, 1);
    Serial.print("  Rover Armed  : "); 
    if (telemetryData.rover_armed == 1) Serial.println("1 (ARMED)");
    else if (telemetryData.rover_armed == 2) Serial.println("2 (PHYSICAL E-STOP)");
    else Serial.println("0 (SOFTWARE DISARM)");
  }
}

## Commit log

2026-06-22 Revise README for Intelligent Power Distribution Unit
    Expanded the README to provide detailed information about the Intelligent Power Distribution Unit, including core features, technical specifications, and repository navigation.
2026-07-19 Update UDP port and voltage reference bug
    [PSU_ADC_readout.ino]
2026-07-23 Implement ADC-based rover armed state detection
    Added telemetry update for rover armed status based on ADC readings.
